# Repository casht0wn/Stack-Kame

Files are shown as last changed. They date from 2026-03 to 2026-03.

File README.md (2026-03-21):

# Stack Kame - Quadruped Robot Controller

A modified mini Kame quadruped robot accessory for Stack-Chan, running on Adafruit Feather ESP32-S3 (no PSRAM) with an 8-channel PWM servo wing. Could also just be a Lego-compatible platform for whatever.

Basically...

Mini Kame ➕ 
Stack-Chan 🟰 
Babyface

..but cute!

⚠️ THIS PROJECT IS A WORK IN PROGRESS ⚠️

## 🦿Hardware

- **Microcontroller**: Adafruit Feather ESP32-S3 (no PSRAM)
- **Servo Controller**: Adafruit 8-channel PWM Servo FeatherWing (PCA9685)
- **Servos**: 8x MG90S digital servos
- **Battery Monitor**: ~~MAX17048 LiPo fuel gauge~~ Not viable: will have to work out a setup with a simple voltage divider going to an analog pin on the feather
- **Physical Design**: Based on miniKame quadruped
  - 3D printed parts
  - M3 machine screws, nuts, and nylock nuts
  - F693ZZ flanged bearings
  - Lego Technic Pins (part # 2780)

I am redesigning the main body to:
- have a lego-compatible mount on top for StackChan
- allow the top cover to be opened without removing the legs
- provide enough space to use an adafruit 8ch PWM wing with right angle headers

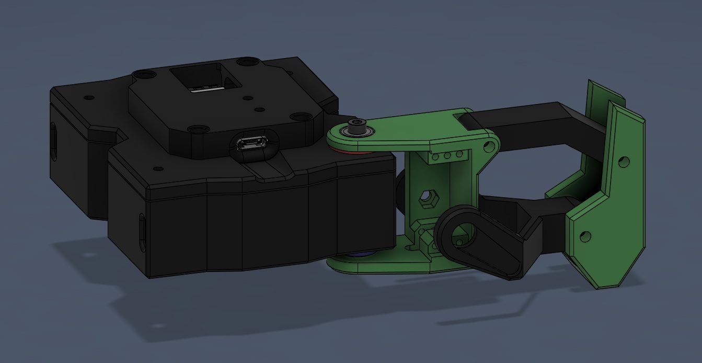
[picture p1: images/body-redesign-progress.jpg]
Body redesign progress


## Firmware

This project contains two PlatformIO firmware modules:

- `firmware/legs-esp32s3` — gait controller for the quadruped body  
- `firmware/controller-cardputer` — handheld remote for driving and testing  

Each folder is a standalone PlatformIO project with its own `platformio.ini`.

## Servo Configuration

```
Servo 0: Front Left Hip
Servo 1: Front Left Foot
Servo 2: Back Left Hip
Servo 3: Back Left Foot
Servo 4: Back Right Hip
Servo 5: Back Right Foot
Servo 6: Front Right Hip
Servo 7: Front Right Foot
```

## Communication Protocols

### 1. ESP-NOW Wireless Control

- **Format**: 2-byte commands
- **Controllers**: M5Stack Cardputer, M5Stack Stack-Chan, or any ESP32 device
- **Pairing**: Auto-accepts commands from any sender (no MAC whitelist)
- **Range**: ~100m line-of-sight (typical ESP-NOW range)

**Command Format**:
- Byte 0: Command type (see command table below)
- Byte 1: Command value (typically number of steps)

**Example (Arduino)**:
```cpp
uint8_t command[2] = {0x02, 5};  // Walk forward 5 steps
esp_now_send(robotMAC, command, 2);
```

### 2. Serial Debugging (USB)

- **Baud Rate**: 115200
- **Interactive Commands**:
  - `h` - Move to home position
  - `z` - Zero all servos (90°)
  - `w` - Walk forward 3 steps
  - `b` - Walk backward 3 steps
  - `t` - Turn left
  - `s` - Emergency stop
  - `r` - Resume from emergency stop
  - `c` - Enter calibration mode
  - `q` - Show queue count

## Command Protocol

| Command | Type | Value | Description |
|---|---|---|---|
| Stop | 0x01 | 0 | Stop movement and return to home |
| Walk Forward | 0x02 | 1-255 | Walk forward N steps |
| Walk Backward | 0x03 | 1-255 | Walk backward N steps |
| Turn Left | 0x04 | 1-255 | Turn left N steps |
| Turn Right | 0x05 | 1-255 | Turn right N steps |
| Moonwalk Forward | 0x06 | 1-255 | Moonwalk forward N steps |
| Moonwalk Backward | 0x07 | 1-255 | Moonwalk backward N steps |
| Jump | 0x08 | 0 | Perform jump animation |
| Shuffle Left | 0x09 | 1-255 | Lateral shuffle left N steps |
| Shuffle Right | 0x0A | 1-255 | Lateral shuffle right N steps |
| Emergency Stop | 0xFF | 0 | Immediate stop all movements |

## Movement Library

The robot uses an oscillator-based movement system inspired by the original miniKame. Each servo is controlled by a sinusoidal oscillator with configurable:

- **Amplitude**: Range of motion in degrees
- **Offset**: Center position offset
- **Phase**: Phase shift for gait coordination
- **Period**: Time for one complete cycle

### Available Gaits

1. **Walk** - Standard alternating tripod gait for forward/backward movement
2. **Turn** - In-place rotation using differential leg movement
3. **Moonwalk** - Smooth sliding motion (Michael Jackson style!)
4. **Lateral Shuffle** - Side-stepping movement
5. **Jump** - Quick up-down animation

## Command Queue

- **Queue Size**: 16 commands
- **Processing**: First-come-first-served (fair arbitration)
- **Priority**: Emergency stop (0xFF) interrupts immediately

## Battery Management - Not *currently* working (pun intended).

- **Low Battery Threshold**: 3.4V or 20% charge
- **Behavior**: Restricts movement commands when battery is low
- **Monitoring**: Checks every 10 seconds
- **Status**: Reported via serial output or can be polled from ESP-NOW

## Servo Calibration

Trim values can be saved to non-volatile storage (Preferences):

```cpp
// Trim values stored as:
preferences.putInt("trim0", value); // -50 to +50 typical range
...
preferences.putInt("trim7", value);
```

- **numbers 0..7**: select a servo
- **+/-**: jog servo forward or back
- **p**: print currently selected servo

**TODO**: Implement interactive calibration interface via serial

## Building and Flashing

```bash
# Using PlatformIO
pio run -t upload

# Monitor serial output
pio device monitor
```

## Example Usage

### Example Usage

```cpp
// From any ESP32 controller (Cardputer or Stack-Chan)
uint8_t command[2] = {0x02, 5}; // Walk forward 5 steps
esp_now_send(robotMAC, command, 2);
```

```cpp
// Turn left 3 steps
uint8_t command[2] = {0x04, 3};
esp_now_send(robotMAC, command, 2);
```

```cpp
// Jump
uint8_t command[2] = {0x08, 0};
esp_now_send(robotMAC, command, 2);
```

## Safety Features

1. **Emergency Stop**: Stops all movements immediately
2. ~~**Low Battery Protection**: Restricts movement on low battery~~ Not yet implemented
3. **Command Queue Overflow**: Warns if queue is full
4. **Servo Limits**: PWM values clamped to safe range (204-410)

## TODO / Future Enhancements

- [ ] Interactive calibration interface via serial
- [ ] MAC address whitelist for ESP-NOW security
- [ ] EEPROM-based movement sequence storage
- [ ] Sensor integration (IMU for balance, ultrasonic for obstacle detection)
- [ ] Smooth movement interpolation between gaits
- [ ] Custom choreographed dance sequences
- [ ] OTA (Over-The-Air) firmware updates
- [ ] New battery monitoring using voltage divider to analog pin

## Credits

- Original miniKame design by Javier Isabel (JavierIH)
- Oscillator-based gait system inspired by Obijuan's work
- Hardware stack by Adafruit Industries

## License

This project inherits the Creative Commons BY-SA license from the original miniKame project.

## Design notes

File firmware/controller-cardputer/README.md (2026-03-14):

# Stack Kame Controller

*for* **M5Stack Cardputer-ADV**

Cardputer-ADV

This is currently a work in progress! ⚠️

The purpose of this firmware is to be able to control a Stack-Kame robot [^1] using an M5Stack Cardputer-ADV. It will be a simple controller with basic movement control as well as calibration and diagnostic information. 

[^1]: Basically a Stack-Chan on top of a mini-Kame quadruped.

## UI Navigation

### Controls
| Key | Function |
|-----|---|
| ⬆️up | move up |
| ⬇️down | move down |
| ⬅️left | move left |
| ➡️right | move right |
| ok/enter | select |
| bksp/del | go back |

### Screens
- Main Menu 
    - Main Controls (`MainControlScreen`)
        - Manual Control of Stack Kame via ESP-NOW commands.
    - Diagnostics (`DiagnosticsScreen`)
        - View Diagnostic info for Stack Kame and the Cardputer such as MAC addresses, battery levels, and RSSI. 
    - Calibration (`CalibrationScreen`)
        - Calibrate servo direction, trims, and end points to ensure Stack Kame walks as desired.

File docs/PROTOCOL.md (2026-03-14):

# Stack Kame Command Protocol Reference

> **Note**: Stack Kame uses ESP-NOW wireless protocol for all control commands.
> Both M5Stack Cardputer and Stack-Chan can control the robot wirelessly.
> Previous I2C slave mode has been removed to simplify bus architecture.

## Quick Command Reference

| Hex  | Dec | Name | Description | Value Range |
|---|-----|---|---|---|
| 0x01 | 1 | STOP | Stop and home | 0 |
| 0x02 | 2 | WALK_FWD | Walk forward | 1-255 steps |
| 0x03 | 3 | WALK_BACK | Walk backward | 1-255 steps |
| 0x04 | 4 | TURN_LEFT | Turn left | 1-255 steps |
| 0x05 | 5 | TURN_RIGHT | Turn right | 1-255 steps |
| 0x06 | 6 | MOON_FWD | Moonwalk forward | 1-255 steps |
| 0x07 | 7 | MOON_BACK | Moonwalk backward | 1-255 steps |
| 0x08 | 8 | JUMP | Jump in place | 0 |
| 0x09 | 9 | SHUFFLE_L | Shuffle left | 1-255 steps |
| 0x0A | 10  | SHUFFLE_R | Shuffle right | 1-255 steps |
| 0x0B | 11  | HOME | Home position | 0 |
| 0x0C | 12  | ZERO | All servos 90 degrees | 0 |
| 0xFF | 255 | E_STOP | Emergency stop | 0 |

## Movement Characteristics

### Walk (0x02, 0x03)
- **Speed**: ~900ms per step
- **Stability**: High
- **Power**: Medium
- **Best for**: General navigation

### Turn (0x04, 0x05)
- **Speed**: ~900ms per step
- **Rotation**: ~30° per step (approximate)
- **Stability**: High
- **Best for**: Direction changes

### Moonwalk (0x06, 0x07)
- **Speed**: ~1000ms per step
- **Stability**: Medium
- **Power**: High
- **Best for**: Show-off moves, smooth motion

### Shuffle (0x09, 0x0A)
- **Speed**: ~900ms per step
- **Stability**: Medium
- **Power**: Medium
- **Best for**: Side-to-side movement

### Jump (0x08)
- **Duration**: ~400ms
- **Stability**: Low (requires level surface)
- **Power**: High
- **Best for**: Celebration, attention-getting

## Status Monitoring

Status information is available via serial monitor output. The robot logs:
- Battery voltage and percentage every 10 seconds
- Command reception and execution
- Movement state changes
- Emergency stop status

Internal status tracking:
- Emergency stop active (triggered by command 0xFF)
- Low battery warning (below threshold)
- Command queue status (0-16 pending commands)

## Timing Guidelines

### Minimum Command Intervals
- Walk/Turn: 3-5 seconds for 3 steps
- Moonwalk: 4-6 seconds for 3 steps
- Shuffle: 3-5 seconds for 3 steps
- Jump: 0.5 seconds

### Queue Management
- Max queue size: 16 commands
- Processing: FIFO (first-come-first-served)
- Queue check: Poll status bit 2

### Battery Life
- Active movement: ~20-30 minutes (varies by battery size)
- Idle (servos at position): ~1-2 hours
- Low battery threshold: 3.4V or 20% charge

## Error Handling

### Robot Won't Move
1. Check emergency stop status (send 'r' via serial or clear e-stop)
2. Check battery level (read status byte bit 1)
3. Check queue full (read status byte bit 2)
4. Verify servo power supply

### Movement Unstable
1. Check servo calibration (adjust trim values)
2. Verify battery voltage >3.7V
3. Reduce step count or speed
4. Check for loose connections

### Command Not Executing
1. Verify I2C/ESP-NOW connection
2. Check command format (2 bytes required)
3. Verify robot not in emergency stop
4. Check serial monitor for error messages

## Example Command Sequences

### Square Pattern
```
Walk Forward (0x02, 5)
Wait 5s
Turn Left (0x04, 2)
Wait 2s
[Repeat 4 times]
```

### Dance Routine
```
Jump (0x08, 0)
Wait 0.5s
Moonwalk Forward (0x06, 2)
Wait 2s
Shuffle Left (0x09, 3)
Wait 3s
Shuffle Right (0x0A, 3)
Wait 3s
Turn Left (0x04, 4) // Spin!
```

### Exploration Pattern
```
Walk Forward (0x02, 10)
Wait 9s
Turn Right (0x05, 3) // Look around
Wait 3s
Walk Forward (0x02, 5)
Wait 5s
Turn Left (0x04, 6) // Head back
```

## Communication Examples

### ESP-NOW Command Format (2 bytes)
```
Data[0]: Command Type (0x01-0xFF)
Data[1]: Value (0-255)
```

**Example in Arduino (Cardputer/Stack-Chan):**
```cpp
uint8_t command[2];
command[0] = 0x02;  // Walk forward
command[1] = 5;     // 5 steps

esp_now_send(robotMAC, command, 2);
```

**Walk forward 3 steps:**
```
Byte 0: 0x02
Byte 1: 0x03
```

**Emergency stop:**
```
Byte 0: 0xFF
Byte 1: 0x00
```

## Debugging via Serial

Connect USB cable and use 115200 baud:

**Keyboard Commands:**
- `h` = Home position
- `z` = Zero servos
- `w` = Walk forward 3
- `b` = Walk backward 3
- `t` = Turn left
- `s` = Emergency stop
- `r` = Resume
- `q` = Show queue count

**Monitor Output:**
- Battery updates every 10s
- Command reception logs
- Movement execution status
- Error messages

## Protocol Extensions (Future)

Ideas for additional commands:
- `0x10-0x1F`: Custom dance sequences
- `0x20-0x2F`: Variable speed control
- `0x30-0x3F`: Sensor readings request
- `0x40-0x4F`: Servo calibration
- `0xF0-0xFE`: Configuration commands

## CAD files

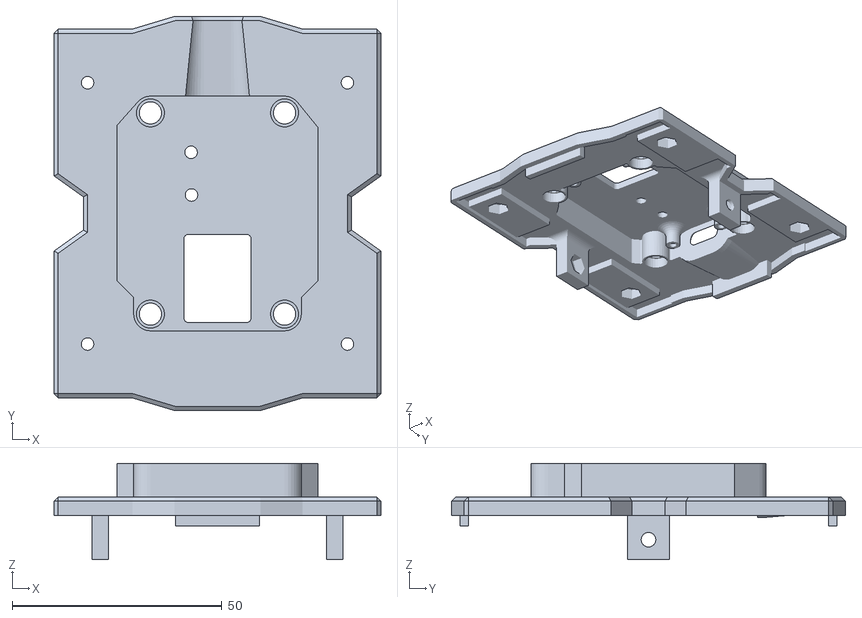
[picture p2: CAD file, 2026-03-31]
cad/topLid.stl
78.0 x 94.0 x 23.0

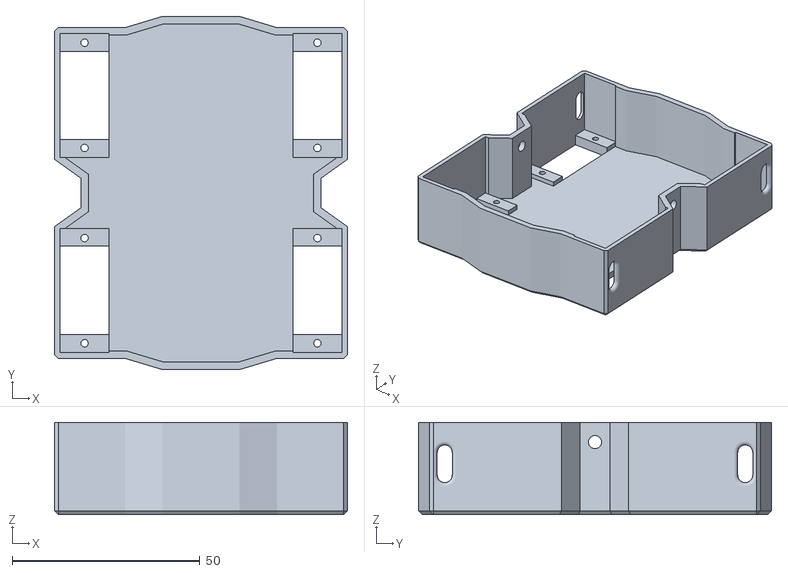
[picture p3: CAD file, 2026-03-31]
cad/bodyTub.stl
78.0 x 94.0 x 24.5

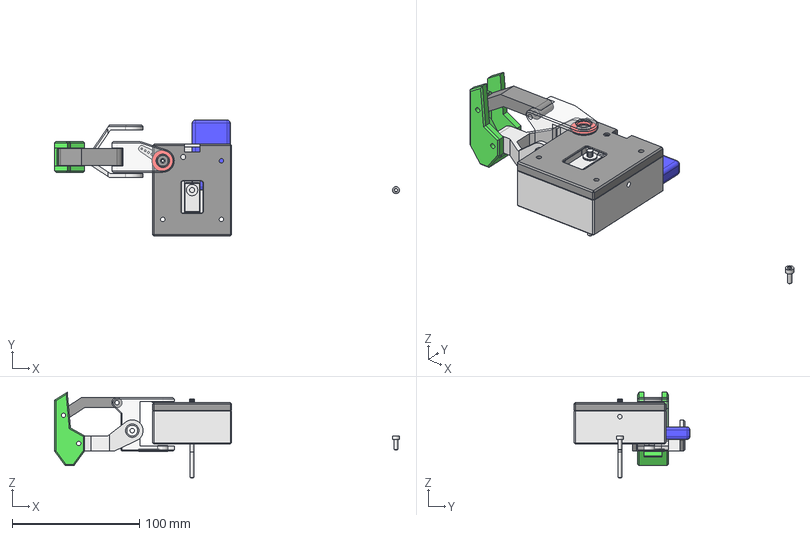
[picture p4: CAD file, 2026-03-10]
cad/stackKame.step
270.8 x 91.0 x 67.2 mm
legB
spacer
bodyA
bodyB
legA
foot
bracket
bearing
horn001
battery
TGY-306G
hex-m3-8mm
m3-nyloc-nut
m3-nut
hex-bolt
hex-m3-30mm
hex-m2-4mm
hex-m2-6mm

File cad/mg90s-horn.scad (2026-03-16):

include <BOSL2/std.scad>
include <BOSL2/gears.scad>

$fn = 100;

// this is somewhere between 0.7-0.8
// depends on fidility of the printer so may be try with couple of options
inner_pitch = 0.7;
teeth_count = 20;
screw_hole_diameter = 2;
hub_diameter = 8;
hub_thickness = 4;
arm_length = 20;
arm_end_width = 5;
arm_thickness = 2;


module horn() {
    tag_scope("horn") {
        diff() {
            cyl(d = hub_diameter, h = hub_thickness/2, anchor = BOTTOM) {
                position(TOP) cyl(d = hub_diameter, h = hub_thickness);
                tag("remove") {
                    position(TOP)
                        spur_gear(circ_pitch = inner_pitch, teeth = teeth_count, thickness = hub_thickness, shaft_diam = 0, anchor = BOTTOM);
                    position(CENTER)
                        cyl(d = screw_hole_diameter, h = hub_thickness*2);
                }
            }

            linear_extrude(height = arm_thickness)
                trapezoid(h = arm_length, w1 = arm_end_width, w2 = hub_diameter, anchor = BACK, rounding = [0, 0, arm_end_width/2, arm_end_width/2]);
        }
    }
}

horn();

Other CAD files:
cad/stackKame.fcstd

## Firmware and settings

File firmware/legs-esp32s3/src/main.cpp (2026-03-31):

#include <Arduino.h>
#include <Wire.h>
#include <esp_now.h>
#include <esp_wifi.h>
#include <WiFi.h>
#include <Preferences.h>
#include "stackkame.h"

#define ESPNOW_CHANNEL 1

// Command IDs shared with controller-cardputer
#define CMD_STOP 0x01
#define CMD_WALK_FORWARD 0x02
#define CMD_WALK_BACKWARD 0x03
#define CMD_TURN_LEFT 0x04
#define CMD_TURN_RIGHT 0x05
#define CMD_MOONWALK_FWD 0x06
#define CMD_MOONWALK_BACK 0x07
#define CMD_JUMP 0x08
#define CMD_SHUFFLE_LEFT 0x09
#define CMD_SHUFFLE_RIGHT 0x0A
#define CMD_HOME 0x0B
#define CMD_ZERO 0x0C
#define CMD_CAL_SELECT_SERVO 0x0D
#define CMD_CAL_JOG_DELTA 0x0E
#define CMD_CAL_SAVE 0x0F
#define CMD_EMERGENCY_STOP 0xFF

// Command Queue
#define QUEUE_SIZE 16
struct Command
{
  byte type;
  byte value;
  unsigned long timestamp;
};

Command commandQueue[QUEUE_SIZE];
int queueHead = 0;
int queueTail = 0;
int queueCount = 0;

// Global objects
StackKame kame;
Preferences preferences;

// State variables
bool emergencyStop = false;
int selectedServo = 0;
int selectedAngle = 90;
int currentTrims[8] = {0, 0, 0, 0, 0, 0, 0, 0};

// Function declarations
void onESPNowReceive(const uint8_t *mac, const uint8_t *data, int len);
bool enqueueCommand(byte type, byte value);
bool dequeueCommand(Command &cmd);
void processCommand(byte type, byte value);
void loadCalibration();
void saveCalibration();

void setup()
{
  Serial.begin(115200);
  unsigned long serialWaitStart = millis();
  while (!Serial && (millis() - serialWaitStart < 5000))
  {
    delay(10);
  }
  Serial.println("\n\nStack Kame Boot Starting...");
  delay(500);

  // Initialize preferences for calibration storage
  Serial.println("[1/5] Initializing preferences...");
  preferences.begin("stackkame", false);
  delay(100);

  // Initialize StackKame servo controller
  Serial.println("[2/5] Initializing servo controller...");
  kame.init();
  delay(100);

  // Set servos to home position
  Serial.println("[3/5] Moving servos to home position...");
  kame.home();
  delay(500);

  // Load calibration from preferences
  Serial.println("[4/5] Loading calibration...");
  loadCalibration();
  delay(100);

  // Initialize ESP-NOW for wireless control (Cardputer + Stack-Chan)
  Serial.println("[5/5] Initializing ESP-NOW...");
  WiFi.mode(WIFI_STA);
  WiFi.disconnect();
  WiFi.setSleep(false);

  uint8_t localMac[6];
  WiFi.macAddress(localMac);
  Serial.printf("Robot STA MAC: %02X:%02X:%02X:%02X:%02X:%02X\n",
                localMac[0], localMac[1], localMac[2], localMac[3], localMac[4], localMac[5]);

  esp_wifi_set_promiscuous(true);
  esp_wifi_set_channel(ESPNOW_CHANNEL, WIFI_SECOND_CHAN_NONE);
  esp_wifi_set_promiscuous(false);
  Serial.printf("ESP-NOW channel locked to: %d\n", ESPNOW_CHANNEL);

  if (esp_now_init() != ESP_OK)
  {
    Serial.println("Error initializing ESP-NOW");
  }
  else
  {
    Serial.println("ESP-NOW initialized");
    esp_err_t cbResult = esp_now_register_recv_cb(onESPNowReceive);
    if (cbResult != ESP_OK)
    {
      Serial.printf("ESP-NOW receive callback registration failed: %d\n", cbResult);
    }
    else
    {
      Serial.println("ESP-NOW receive callback registered");
    }
  }
  delay(100);

  Serial.println("\n=== Stack Kame Ready ===");
  Serial.println("Serial commands: h=home, z=zero, w=walk, t=turn, s=stop, r=resume, q=queue");
  Serial.println("Calibration: 0-7=select servo, +=jog +5, -=jog -5, p=print selected");
  Serial.println("ESP-NOW calibration: 0x0D select servo, 0x0E jog signed delta");
  Serial.println("Waiting for commands...\n");
}

void loop()
{
  // Update oscillators for smooth movements
  kame.update();

  // Process command queue
  if (queueCount > 0 && !emergencyStop)
  {
    Command cmd;
    if (dequeueCommand(cmd))
    {
      processCommand(cmd.type, cmd.value);
    }
  }

  // Handle serial commands for debugging
  if (Serial.available() > 0)
  {
    char cmd = Serial.read();
    switch (cmd)
    {
    case 'h':
      Serial.println("Moving to home position");
      kame.home();
      break;
    case 'z':
      Serial.println("Zeroing servos");
      kame.zero();
      break;
    case 's':
      Serial.println("Emergency stop!");
      emergencyStop = true;
      kame.stopMovement();
      break;
    case 'r':
      Serial.println("Resume operation");
      emergencyStop = false;
      break;
    case 'c':
      Serial.println("Entering calibration mode - send trim values");
      // TODO: Implement interactive calibration
      break;
    case 'w':
      Serial.println("Walk forward 3 steps");
      enqueueCommand(0x02, 3);
      break;
    case 'b':
      Serial.println("Walk backward 3 steps");
      enqueueCommand(0x03, 3);
      break;
    case 't':
      Serial.println("Turn left");
      enqueueCommand(0x04, 1);
      break;
    case 'q':
      Serial.print("Queue count: ");
      Serial.println(queueCount);
      break;
    case '+':
      selectedAngle = constrain(selectedAngle + 5, 0, 180);
      Serial.print("Jog servo ");
      Serial.print(selectedServo);
      Serial.print(" to ");
      Serial.println(selectedAngle);
      kame.setServo(selectedServo, selectedAngle);
      break;
    case '-':
      selectedAngle = constrain(selectedAngle - 5, 0, 180);
      Serial.print("Jog servo ");
      Serial.print(selectedServo);
      Serial.print(" to ");
      Serial.println(selectedAngle);
      kame.setServo(selectedServo, selectedAngle);
      break;
    case 'p':
      Serial.print("Selected servo: ");
      Serial.print(selectedServo);
      Serial.print(", angle: ");
      Serial.println(selectedAngle);
      break;
    case '0':
    case '1':
    case '2':
    case '3':
    case '4':
    case '5':
    case '6':
    case '7':
      selectedServo = cmd - '0';
      selectedAngle = 90;
      Serial.print("Selected servo ");
      Serial.print(selectedServo);
      Serial.println(" (set to 90)");
      kame.setServo(selectedServo, selectedAngle);
      break;
    }
  }

  delay(10); // Small delay to prevent overwhelming the system
}

// ESP-NOW Receive Callback - receives commands from Cardputer or Stack-Chan
void onESPNowReceive(const uint8_t *mac, const uint8_t *data, int len)
{
  if (len >= 2)
  {
    byte cmdType = data[0];
    byte cmdValue = data[1];

    Serial.print("ESP-NOW Command from: ");
    for (int i = 0; i < 6; i++)
    {
      Serial.printf("%02X", mac[i]);
      if (i < 5)
        Serial.print(":");
    }
    Serial.print(" - Type: 0x");
    Serial.print(cmdType, HEX);
    Serial.print(" Value: ");
    Serial.println(cmdValue);

    enqueueCommand(cmdType, cmdValue);
  }
}

// Add command to queue
bool enqueueCommand(byte type, byte value)
{
  if (queueCount >= QUEUE_SIZE)
  {
    Serial.println("Warning: Command queue full!");
    return false;
  }

  commandQueue[queueTail].type = type;
  commandQueue[queueTail].value = value;
  commandQueue[queueTail].timestamp = millis();

  queueTail = (queueTail + 1) % QUEUE_SIZE;
  queueCount++;

  return true;
}

// Remove command from queue
bool dequeueCommand(Command &cmd)
{
  if (queueCount == 0)
  {
    return false;
  }

  cmd = commandQueue[queueHead];
  queueHead = (queueHead + 1) % QUEUE_SIZE;
  queueCount--;

  return true;
}

// Process a movement command
void processCommand(byte type, byte value)
{
  if (emergencyStop)
  {
    Serial.println("Emergency stop active - command ignored");
    return;
  }

  Serial.print("Processing command: 0x");
  Serial.print(type, HEX);
  Serial.print(" Value: ");
  Serial.println(value);

  switch (type)
  {
  case CMD_STOP: // Stop
    kame.stopMovement();
    kame.home();
    Serial.println("Stop & Home");
    break;

  case CMD_WALK_FORWARD: // Walk forward
  {
    int steps = (value > 0) ? value : 1;
    Serial.print("Walk forward ");
    Serial.print(steps);
    Serial.println(" steps");
    kame.walk(steps, 900, false);
  }
  break;

  case CMD_WALK_BACKWARD: // Walk backward
  {
    int steps = (value > 0) ? value : 1;
    Serial.print("Walk backward ");
    Serial.print(steps);
    Serial.println(" steps");
    kame.walk(steps, 900, true);
  }
  break;

  case CMD_TURN_LEFT: // Turn left
  {
    int steps = (value > 0) ? value : 1;
    Serial.print("Turn left ");
    Serial.print(steps);
    Serial.println(" steps");
    kame.turn(steps, 900, true);
  }
  break;

  case CMD_TURN_RIGHT: // Turn right
  {
    int steps = (value > 0) ? value : 1;
    Serial.print("Turn right ");
    Serial.print(steps);
    Serial.println(" steps");
    kame.turn(steps, 900, false);
  }
  break;

  case CMD_MOONWALK_FWD: // Moonwalk forward
  {
    int steps = (value > 0) ? value : 1;
    Serial.print("Moonwalk forward ");
    Serial.print(steps);
    Serial.println(" steps");
    kame.moonwalk(steps, 1000, false);
  }
  break;

  case CMD_MOONWALK_BACK: // Moonwalk backward
  {
    int steps = (value > 0) ? value : 1;
    Serial.print("Moonwalk backward ");
    Serial.print(steps);
    Serial.println(" steps");
    kame.moonwalk(steps, 1000, true);
  }
  break;

  case CMD_JUMP: // Jump
    Serial.println("Jump!");
    kame.jump();
    break;

  case CMD_SHUFFLE_LEFT: // Lateral shuffle left
  {
    int steps = (value > 0) ? value : 1;
    Serial.print("Lateral shuffle left ");
    Serial.print(steps);
    Serial.println(" steps");
    kame.lateral_fuerte(true, steps, 900);
  }
  break;

  case CMD_SHUFFLE_RIGHT: // Lateral shuffle right
  {
    int steps = (value > 0) ? value : 1;
    Serial.print("Lateral shuffle right ");
    Serial.print(steps);
    Serial.println(" steps");
    kame.lateral_fuerte(false, steps, 900);
  }
  break;

  case CMD_HOME: // home position
  {
    Serial.println("Moving to home position");
    kame.home();
  }
  break;

  case CMD_ZERO: // zero position
  {
    Serial.println("Zeroing servos");
    kame.zero();
  }
  break;

  case CMD_CAL_SELECT_SERVO:
  {
    selectedServo = constrain(static_cast<int>(value), 0, 7);
    selectedAngle = 90;
    // Zero this servo's trim so jogging reflects raw mechanical position
    currentTrims[selectedServo] = 0;
    kame.setTrims(currentTrims[0], currentTrims[1], currentTrims[2], currentTrims[3],
                  currentTrims[4], currentTrims[5], currentTrims[6], currentTrims[7]);
    Serial.print("Calibration select servo ");
    Serial.println(selectedServo);
    kame.setServo(selectedServo, selectedAngle);
  }
  break;

  case CMD_CAL_JOG_DELTA:
  {
    int8_t delta = static_cast<int8_t>(value);
    delta = constrain(static_cast<int>(delta), -20, 20);
    selectedAngle = constrain(selectedAngle + delta, 0, 180);
    Serial.print("Calibration jog servo ");
    Serial.print(selectedServo);
    Serial.print(" by ");
    Serial.print(delta);
    Serial.print(" -> ");
    Serial.println(selectedAngle);
    kame.setServo(selectedServo, selectedAngle);
  }
  break;

  case CMD_CAL_SAVE:
  {
    currentTrims[selectedServo] = selectedAngle - 90;
    kame.setTrims(currentTrims[0], currentTrims[1], currentTrims[2], currentTrims[3],
                  currentTrims[4], currentTrims[5], currentTrims[6], currentTrims[7]);
    saveCalibration();
    Serial.print("Saved trim for servo ");
    Serial.print(selectedServo);
    Serial.print(": ");
    Serial.println(currentTrims[selectedServo]);
  }
  break;

  case CMD_EMERGENCY_STOP: // Emergency stop
    Serial.println("Emergency Stop Command!");
    emergencyStop = true;
    kame.stopMovement();
    break;

  default:
    Serial.print("Unknown command: 0x");
    Serial.println(type, HEX);
    break;
  }
}

// Load servo trim calibration from preferences
void loadCalibration()
{
  char key[8];
  for (int i = 0; i < 8; i++)
  {
    snprintf(key, sizeof(key), "trim%d", i);
    currentTrims[i] = preferences.getInt(key, 0);
  }

  kame.setTrims(currentTrims[0], currentTrims[1], currentTrims[2], currentTrims[3],
                currentTrims[4], currentTrims[5], currentTrims[6], currentTrims[7]);

  Serial.println("Calibration loaded from preferences");
  Serial.print("Trims: ");
  for (int i = 0; i < 8; i++)
  {
    if (i > 0) Serial.print(", ");
    Serial.print(currentTrims[i]);
  }
  Serial.println();
}

// Save servo trim calibration to preferences
void saveCalibration()
{
  char key[8];
  for (int i = 0; i < 8; i++)
  {
    snprintf(key, sizeof(key), "trim%d", i);
    preferences.putInt(key, currentTrims[i]);
  }
  Serial.println("Calibration saved to preferences");
}

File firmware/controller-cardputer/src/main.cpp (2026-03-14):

#include <M5Cardputer.h>
#include <M5Unified.h>
#include <WiFi.h>

#include <app_state.h>
#include <communication.h>
#include <screens.h>

namespace
{
constexpr uint8_t ESPNOW_CHANNEL = 1;
constexpr unsigned long INPUT_REPEAT_DELAY_MS = 260;
constexpr unsigned long INPUT_REPEAT_MS = 90;

const uint8_t ROBOT_MAC[6] = {0xF0, 0x9E, 0x9E, 0x74, 0x92, 0x88};

AppState appState;
CommandSender sender;

KeyInput decodeKeyInput()
{
  KeyInput input;

  if (!M5Cardputer.Keyboard.isPressed())
  {
    return input;
  }

  input.pressed = true;
  const Keyboard_Class::KeysState status = M5Cardputer.Keyboard.keysState();

  String keyStr;
  for (const auto token : status.word)
  {
    if (!keyStr.isEmpty())
    {
      keyStr += "+";
    }
    keyStr += token;
  }

  /**
   * UI Navigation: uses the "arrow keys" but ignoring the fn modifier since it's hard to press together. 
   * The number keys set the speed level in the controls screen.
   */
  if (keyStr == ";" || keyStr == "w" || keyStr == "W") // ";" = Up arrow key on M5Stack Cardputer-ADV keyboard
  {
    input.action = Action::Up;
  }
  else if (keyStr == "." || keyStr == "s" || keyStr == "S") // "." = Down arrow key on M5Stack Cardputer-ADV keyboard
  {
    input.action = Action::Down;
  }
  else if (keyStr == "," || keyStr == "a" || keyStr == "A") // "," = Left arrow key on M5Stack Cardputer-ADV keyboard
  {
    input.action = Action::Left;
  }
  else if (keyStr == "/" || keyStr == "d" || keyStr == "D") // "/" = Right arrow key on M5Stack Cardputer-ADV keyboard
  {
    input.action = Action::Right;
  }
  else if (keyStr == "h" || keyStr == "H" ) // (On Controls screen) Send robot to "home" position
  {
    input.action = Action::Home;
  }
  else if (keyStr == "`" || keyStr == "x" || keyStr == "X") // "`" = Escape key on M5Stack Cardputer-ADV keyboard
  {
    input.action = Action::Emergency;
  }
  else if (keyStr.length() == 1 && keyStr[0] >= '0' && keyStr[0] <= '9')
  {
    input.number = keyStr[0] - '0';
  }

  if (status.enter)
  {
    input.action = Action::Select;
  }
  else if (status.del)
  {
    input.action = Action::Back;
  }

  return input;
}

bool isCalibrationJogInput(const KeyInput &input, const AppState &state)
{
  if (state.activeScreen != ScreenId::Calibration)
  {
    return false;
  }

  return input.action == Action::Left ||
         input.action == Action::Right ||
         input.action == Action::Up ||
         input.action == Action::Down;
}

void resetRepeatState(AppState &state)
{
  state.heldAction = Action::None;
  state.heldNumber = -1;
  state.lastRepeatMs = 0;
  state.repeatActive = false;
}

KeyInput readKeyInput(AppState &state, unsigned long now)
{
  KeyInput input = decodeKeyInput();
  if (!input.pressed)
  {
    resetRepeatState(state);
    return input;
  }

  const bool changed = M5Cardputer.Keyboard.isChange();
  const bool sameInput = (input.action == state.heldAction && input.number == state.heldNumber);
  if (changed || !sameInput)
  {
    state.heldAction = input.action;
    state.heldNumber = input.number;
    state.lastRepeatMs = now;
    state.repeatActive = false;
    return input;
  }

  if (isCalibrationJogInput(input, state))
  {
    const unsigned long interval = state.repeatActive ? INPUT_REPEAT_MS : INPUT_REPEAT_DELAY_MS;
    if (now - state.lastRepeatMs >= interval)
    {
      state.lastRepeatMs = now;
      state.repeatActive = true;
      return input;
    }
  }

  return KeyInput{};
}

bool macIsUnset(const uint8_t mac[6])
{
  for (size_t i = 0; i < 6; ++i)
  {
    if (mac[i] != 0)
    {
      return false;
    }
  }

  return true;
}
} // namespace

void setup()
{
  auto cfg = M5.config();
  M5Cardputer.begin(cfg);
  M5Cardputer.Display.setRotation(1);
  M5Cardputer.Display.setTextSize(1);

  Serial.begin(115200);
  delay(200);

  if (macIsUnset(ROBOT_MAC))
  {
    M5Cardputer.Display.fillScreen(BLACK);
    M5Cardputer.Display.setCursor(8, 12);
    M5Cardputer.Display.println("Set ROBOT_MAC in main.cpp");
    Serial.println("ERROR: ROBOT_MAC is unset.");
    return;
  }

  uint8_t localMac[6];
  WiFi.macAddress(localMac);
  Serial.printf("Cardputer MAC: %02X:%02X:%02X:%02X:%02X:%02X\n",
                localMac[0], localMac[1], localMac[2], localMac[3], localMac[4], localMac[5]);

  if (!sender.begin(ROBOT_MAC, ESPNOW_CHANNEL))
  {
    M5Cardputer.Display.fillScreen(BLACK);
    M5Cardputer.Display.setCursor(8, 12);
    M5Cardputer.Display.println("ESP-NOW setup failed");
    return;
  }

  appState.diagnostics.addLog("Controller booted");
  appState.diagnostics.addLog("ESP-NOW ready");
  appState.needsRedraw = true;
}

void loop()
{
  M5Cardputer.update();

  refreshDiagnostics(appState);

  const unsigned long now = millis();
  const KeyInput input = readKeyInput(appState, now);
  if (input.pressed)
  {
    appState.lastInputMs = now;
    handleInput(input, appState, sender);
  }

  if (appState.needsRedraw)
  {
    drawActiveScreen(appState);
    appState.needsRedraw = false;
  }

  delay(10);
}

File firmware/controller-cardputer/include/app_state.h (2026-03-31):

#pragma once

#include <Arduino.h>

enum class ScreenId
{
    Menu,
    Controls,
    Diagnostics,
    Calibration,
};

enum class Action
{
    None,
    Up,
    Down,
    Left,
    Right,
    Select,
    Back,
    Emergency,
    Home,
    Zero,
};

struct KeyInput
{
    Action action = Action::None;
    int number = -1;
    bool pressed = false;
};

struct MenuState
{
    int selected = 0;
};

struct ControlsState
{
    uint8_t speed = 1;
};

struct CommandFeedbackState
{
    String label;
    bool success = true;
    bool hasValue = false;
    unsigned long updatedMs = 0;
};

struct DiagnosticsState
{
    static constexpr size_t LOG_CAPACITY = 8;

    int batteryPercent = 0;
    int rssiDbm = 0;
    uint32_t uptimeSec = 0;

    String logs[LOG_CAPACITY];
    size_t logCount = 0;

    void addLog(const String &line)
    {
        if (logCount < LOG_CAPACITY)
        {
            logs[logCount++] = line;
            return;
        }

        for (size_t i = 1; i < LOG_CAPACITY; ++i)
        {
            logs[i - 1] = logs[i];
        }
        logs[LOG_CAPACITY - 1] = line;
    }
};

struct CalibrationState
{
    uint8_t selectedServo = 0;
    int selectedAngle = 90;
    int trims[8] = {0, 0, 0, 0, 0, 0, 0, 0}; // saved trim per servo (degrees from center)
};

struct AppState
{
    ScreenId activeScreen = ScreenId::Menu;
    MenuState menu;
    ControlsState controls;
    CommandFeedbackState commandFeedback;
    DiagnosticsState diagnostics;
    CalibrationState calibration;
    unsigned long lastInputMs = 0;
    unsigned long lastDiagnosticsRefreshMs = 0;
    unsigned long lastRepeatMs = 0;
    Action heldAction = Action::None;
    int heldNumber = -1;
    bool repeatActive = false;
    bool needsRedraw = true;
};

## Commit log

2026-03-07 feat: Add Stack Kame control examples and core functionality
    - Introduced `controller_examples.ino` for ESP-NOW communication with Stack Kame.
    - Created `stackkame.h` and `stackkame.cpp` for managing servo controls and movements.
    - Implemented `Oscillator` class for smooth servo movements in `Oscillator.h` and `Oscillator.cpp`.
    - Added I2C communication support for Stack-Chan in `main.cpp`.
    - Established command queue system for handling movement commands.
    - Integrated battery monitoring using MAX17048.
    - Added calibration storage using Preferences library.
    - Included README files for project structure and library usage.
    - Set up PlatformIO configuration in `platformio.ini`.
    [main.cpp, stackkame.cpp]
2026-03-07 Refactor code for improved readability and consistency
    - Standardized formatting by removing unnecessary whitespace and aligning code blocks.
    - Updated function definitions and implementations in `Oscillator` and `StackKame` classes for better clarity.
    - Added a new binary FreeCAD file `stackKame.fcstd` to the project.
    - Enhanced command processing logic in `main.cpp` for better structure and readability.
    - Improved battery check and calibration loading functions for clearer output and logic flow.
    [stackKame.fcstd]
2026-03-08 feat: Update communication protocol to ESP-NOW and remove I2C support; refactor controller examples and stackkame implementation
2026-03-10 Refactor battery management and servo initialization
    - Removed the Adafruit_MAX17048 battery monitor integration and related checks.
    - Simplified I2C initialization by removing specific pin configurations.
    - Adjusted servo home position logic in StackKame class.
    - Updated command processing to include new home and zero position commands.
    - Cleaned up unnecessary battery status checks and low battery flags.
    [stackKame.fcstd, stackKame.step]
2026-03-12 feat: Enhance servo control with jog and selection commands; update home position logic and servo limits
2026-03-13 feat: Update README and examples for battery management and ESP-NOW setup; improve servo control logic and calibration
    [stackKame.fcstd]
2026-03-13 feat: Update README with images and enhance safety features; adjust servo limits and add battery monitoring to TODO
2026-03-14 Restructured repo to accommodate controller firmware as second PlatformIO project.
    [stackKame.fcstd, stackKame.step]
2026-03-14 feat: Add .gitignore and extensions.json for controller-cardputer and legs-esp32s3 directories
2026-03-14 Add command handling and communication for robot control
    - Introduced command definitions in commands.h for robot actions.
    - Implemented CommandSender class in communication.h and communication.cpp for ESP-NOW communication.
    - Created screens.h and screens.cpp for managing UI screens and input handling.
    - Removed ui_widgets.h as it was no longer needed.
    - Updated main.cpp to integrate new command handling and screen management.
    - Enhanced processCommand function in legs-esp32s3 to handle new commands and calibration features.
    [app_state.h, communication.cpp, main.cpp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]
2026-03-15 fix: Correct servo pin definitions and update home position offsets for improved movement control
    [stackkame.cpp]
2026-03-16 Further refined main body. Add a parametric servo horn. Add body redesign progress image.
    [mg90s-horn.scad]
2026-03-31 feat: Add new body and top lid STL files, update redesign progress image
    [bodyTub.stl, topLid.stl]
2026-03-31 feat: Add trim saving functionality for servo calibration
